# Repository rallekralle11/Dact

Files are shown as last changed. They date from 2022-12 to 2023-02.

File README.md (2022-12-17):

# Dact

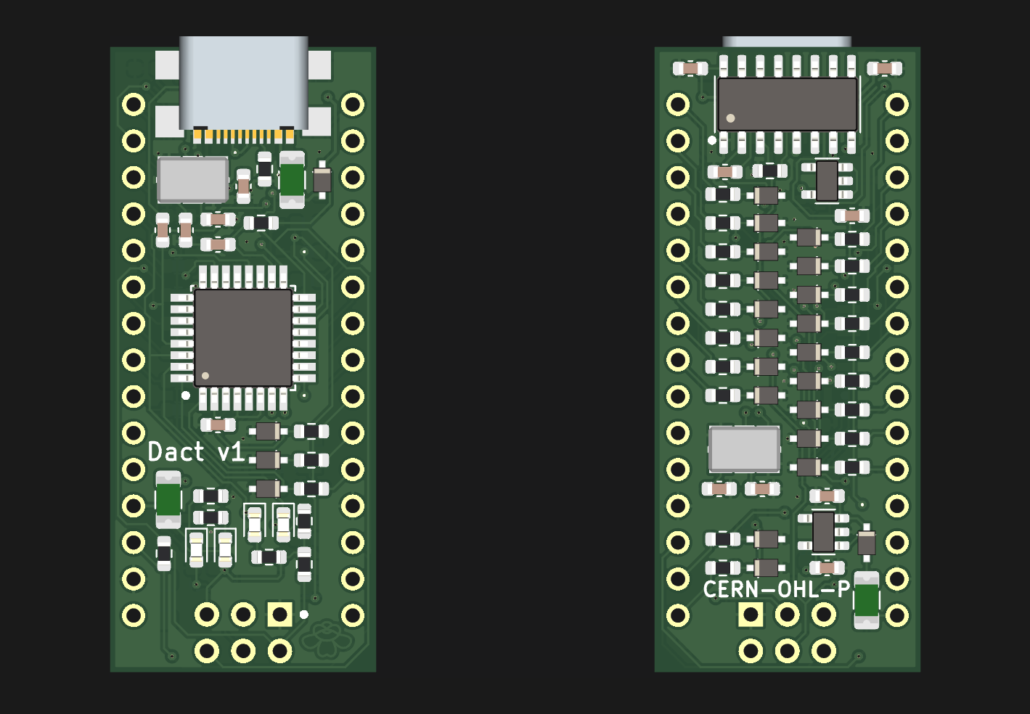
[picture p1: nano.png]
board


With overcurrent(short) and overvoltage protection on all IO pins, VIN reverse polarity and short protection, USB and MCU overcurrent protection as well as reset pin overvoltage protection. And USB-C.

Lacks 5 and 3V pin overvoltage protection, i tried but it wouldn't fit. Amazed i managed to fit this many features on it in general, and with 1608 components as well.

Of course there are tradeoffs, the onboard 5V regulator can only supply 150mA, there's no reset button and there's no way i could fit all pin identifiers, so i didn't add any.

Licensed under CERN-OHL-P

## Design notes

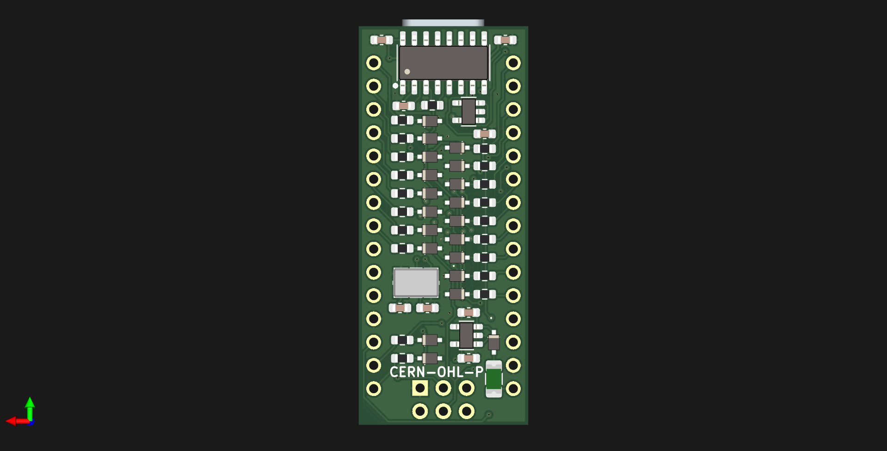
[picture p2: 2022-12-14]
DactB.png

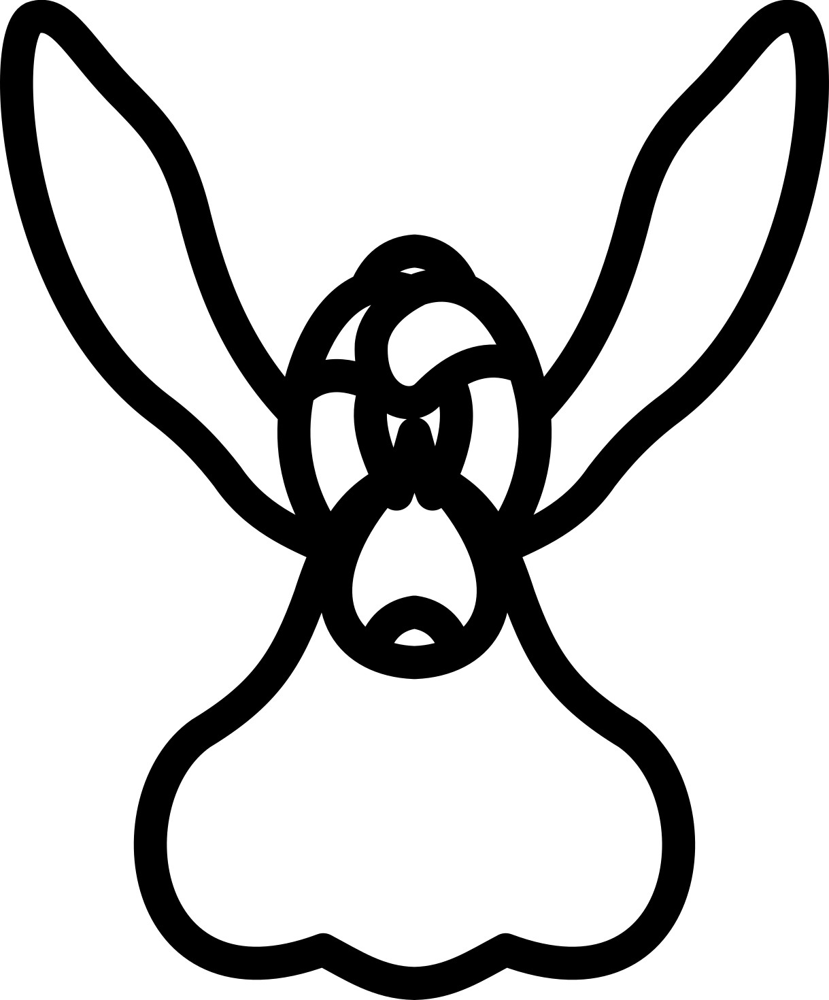
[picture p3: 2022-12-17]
maculata.png

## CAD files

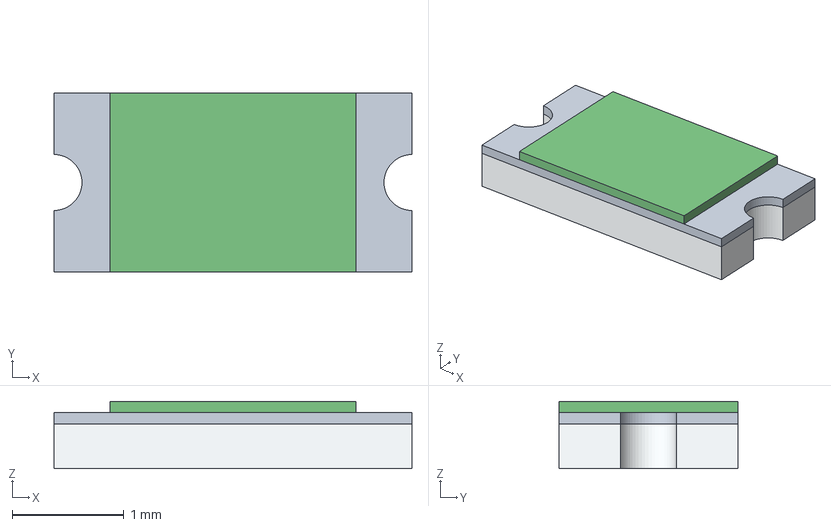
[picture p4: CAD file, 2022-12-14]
fuse.stp
3.20 x 1.60 x 0.6 mm

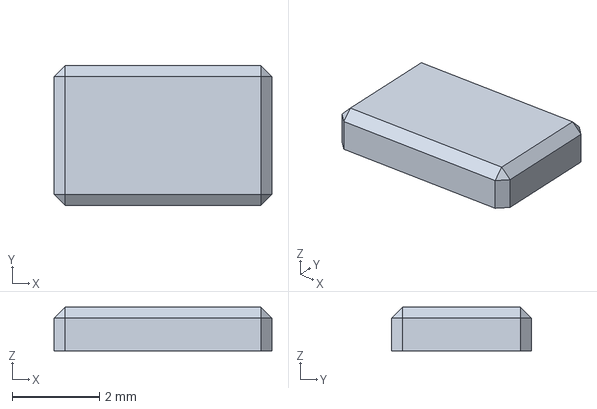
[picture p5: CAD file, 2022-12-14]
crystal.stp
5.00 x 3.20 x 1.00 mm

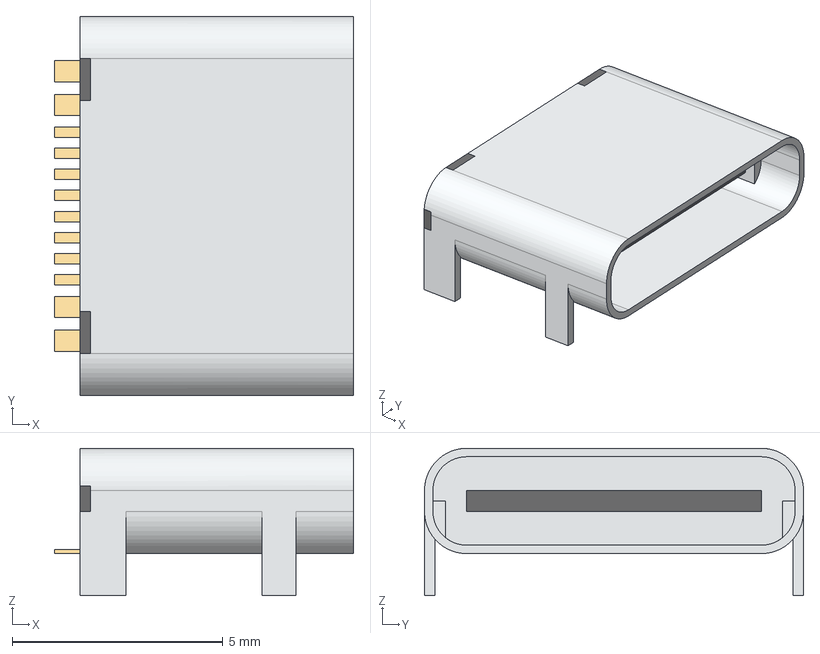
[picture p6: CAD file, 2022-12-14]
USBC.stp
7.10 x 9.00 x 3.50 mm

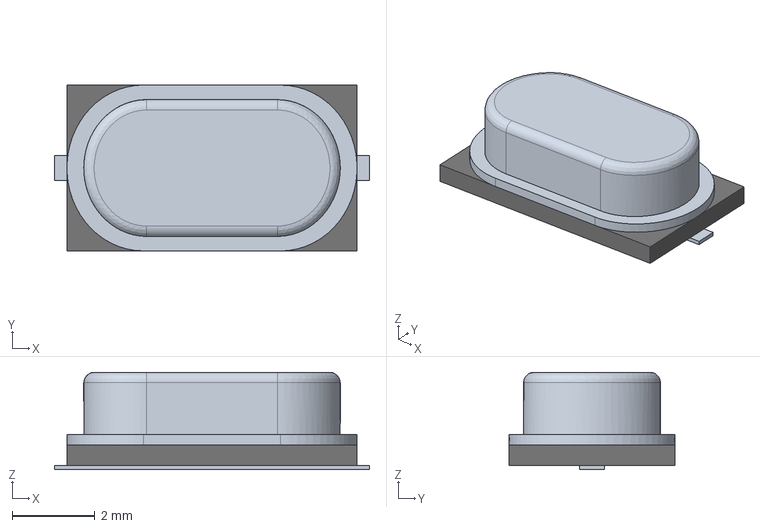
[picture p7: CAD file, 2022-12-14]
crystal2.stp
7.60 x 4.00 x 2.35 mm

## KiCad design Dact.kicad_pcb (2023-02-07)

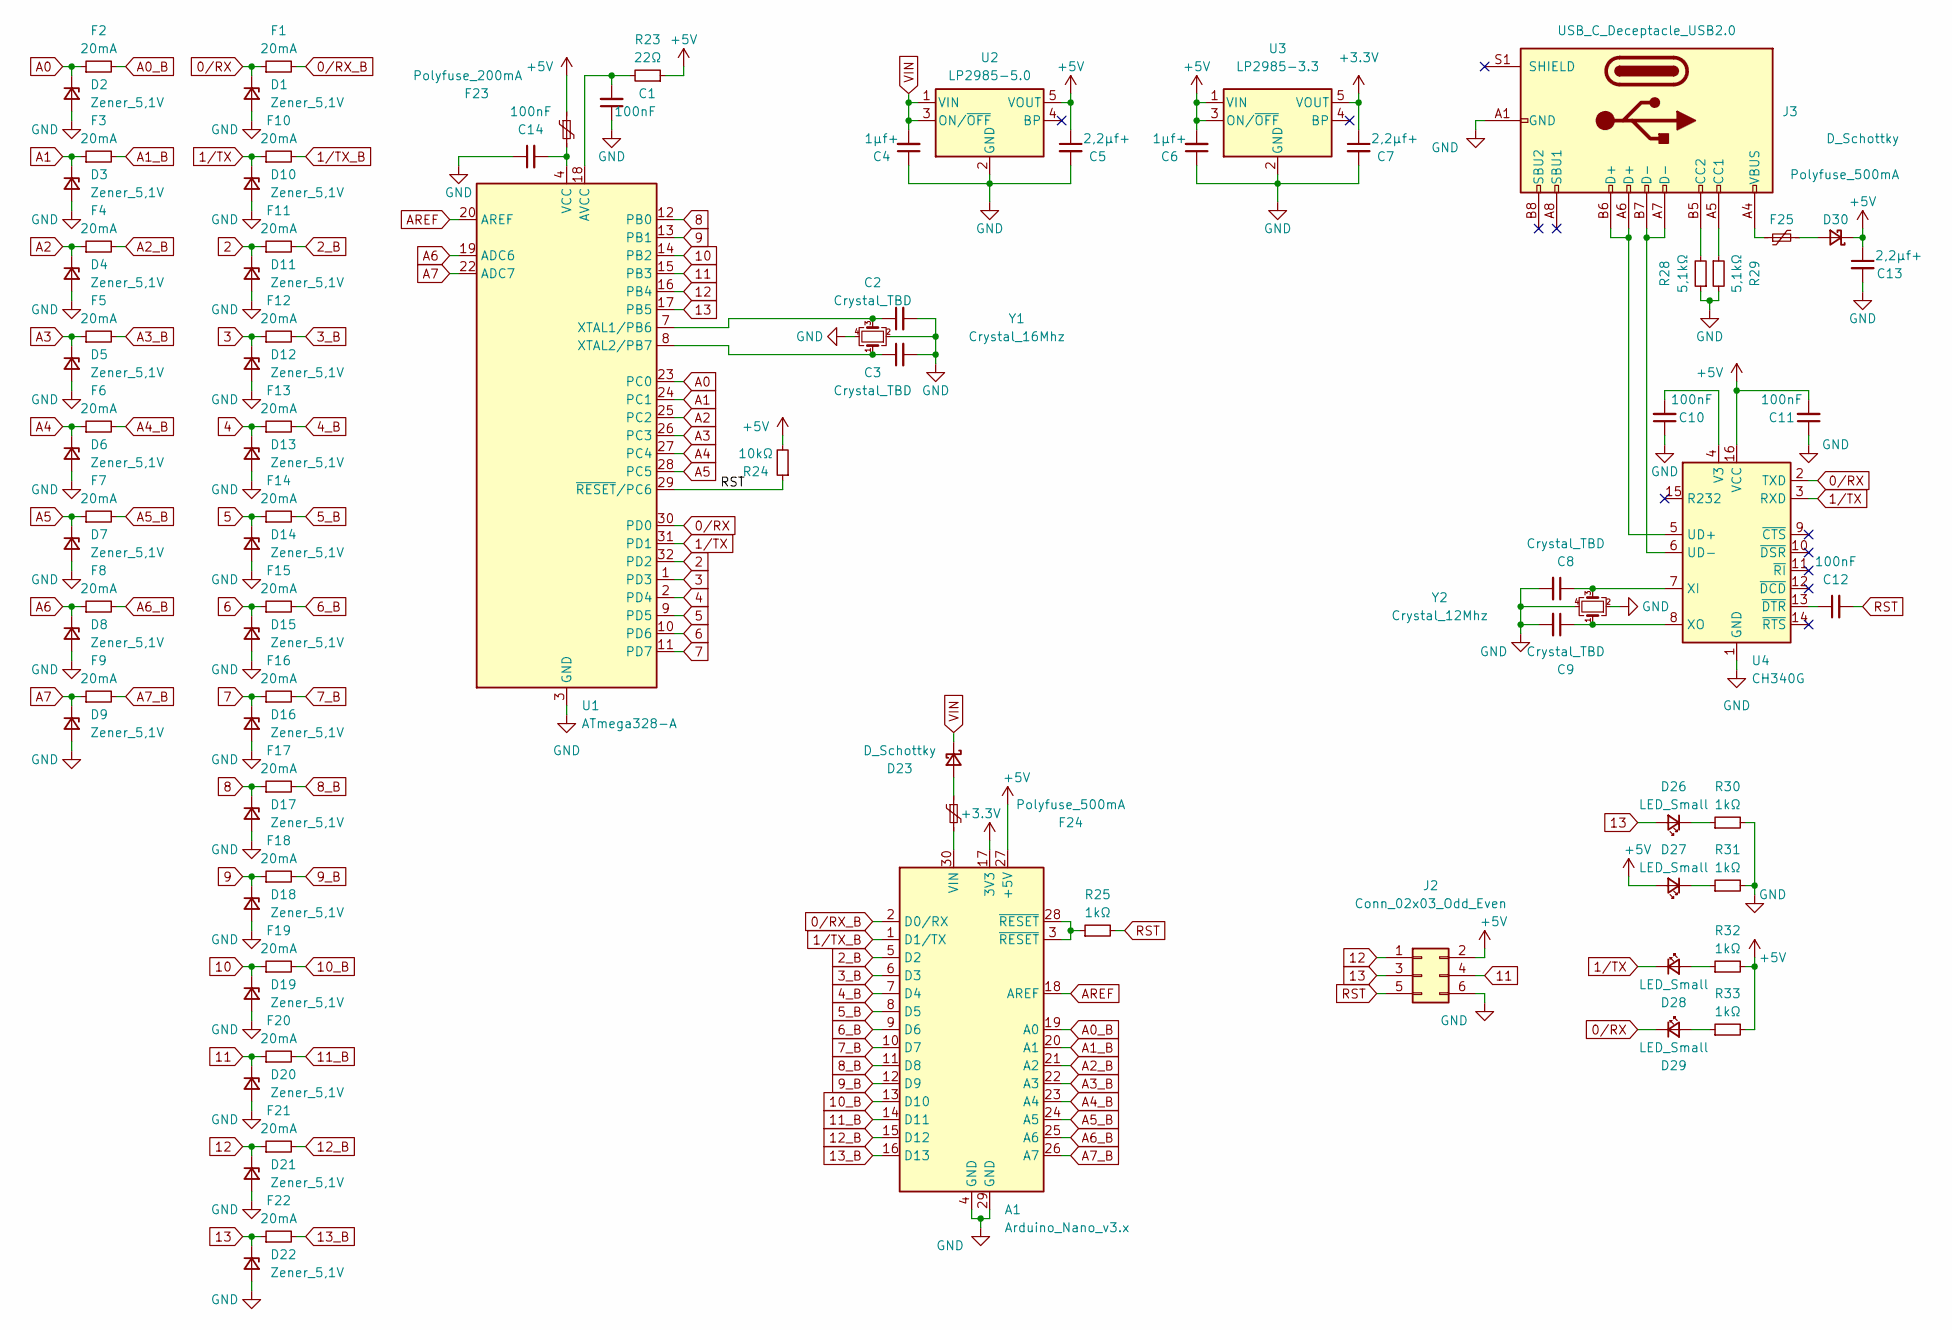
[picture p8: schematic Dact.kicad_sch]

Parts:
A1: Arduino_Nano_v3.x; Arduino_Nano
C1, C10, C11, C12, C14: 100nF; C_0603_1608Metric
C2, C3, C8, C9: Crystal_TBD; C_0603_1608Metric
C4, C6: 1µf+; C_0603_1608Metric
C5, C7, C13: 2,2µf+; C_0603_1608Metric
D1, D2, D3, D4, D5, D6, D7, D8, D9, D10, D11, D12, D13, D14, D15, D16, D17, D18, D19, D20, D21, D22: Zener_5,1V; SOD323_bättre
D23, D30: D_Schottky; SOD323_bättre
D26, D27, D28, D29: LED_Small; LED_0603_1608Metric
F1, F2, F3, F4, F5, F6, F7, F8, F9, F10, F11, F12, F13, F14, F15, F16, F17, F18, F19, F20, F21, F22: 20mA; R_0603_1608Metric
F23: Polyfuse_200mA; Fuse_1206_3216Metric
F24, F25: Polyfuse_500mA; Fuse_1206_3216Metric
J2: Conn_02x03_Odd_Even; PinHeader_2x03_P2.54mm_Vertical
J3: USB_C_Deceptacle_USB2.0; TYPE-C-SMD
R23: 22Ω; R_0603_1608Metric
R24: 10kΩ; R_0603_1608Metric
R25, R30, R31, R32, R33: 1kΩ; R_0603_1608Metric
R28, R29: 5,1kΩ; R_0603_1608Metric
U1: ATmega328-A; TQFP-32_7x7mm_P0.8mm
U2: LP2985-5.0; SOT-23-5
U3: LP2985-3.3; SOT-23-5
U4: CH340G; SOIC-16_3.9x9.9mm_P1.27mm
Y1: Crystal_16Mhz; Crystal_SMD_5032-4Pin_5.0x3.2mm
Y2: Crystal_12Mhz; Crystal_SMD_5032-4Pin_5.0x3.2mm

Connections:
0/RX: D1.1 (K), D29.1 (K), F1.1, U1.30 (PD0), U4.2 (TXD)
0/RX_B: A1.2 (D0/RX), F1.2
1/TX: D10.1 (K), D28.1 (K), F10.1, U1.31 (PD1), U4.3 (RXD)
1/TX_B: A1.1 (D1/TX), F10.2
2: D11.1 (K), F11.1, U1.32 (PD2)
2_B: A1.5 (D2), F11.2
3: D12.1 (K), F12.1, U1.1 (PD3)
3_B: A1.6 (D3), F12.2
4: D13.1 (K), F13.1, U1.2 (PD4)
4_B: A1.7 (D4), F13.2
5: D14.1 (K), F14.1, U1.9 (PD5)
5_B: A1.8 (D5), F14.2
6: D15.1 (K), F15.1, U1.10 (PD6)
6_B: A1.9 (D6), F15.2
7: D16.1 (K), F16.1, U1.11 (PD7)
7_B: A1.10 (D7), F16.2
8: D17.1 (K), F17.1, U1.12 (PB0)
8_B: A1.11 (D8), F17.2
9: D18.1 (K), F18.1, U1.13 (PB1)
9_B: A1.12 (D9), F18.2
10: D19.1 (K), F19.1, U1.14 (PB2)
10_B: A1.13 (D10), F19.2
11: D20.1 (K), F20.1, J2.4, U1.15 (PB3)
11_B: A1.14 (D11), F20.2
12: D21.1 (K), F21.1, J2.1, U1.16 (PB4)
12_B: A1.15 (D12), F21.2
13: D22.1 (K), D26.2 (A), F22.1, J2.3, U1.17 (PB5)
13_B: A1.16 (D13), F22.2
+3.3V: A1.17 (3V3), C7.1, U3.5 (VOUT)
+5V: A1.27 (+5V), C5.1, C6.2, C11.2, C13.1, D27.2 (A), D30.1 (K), F23.1, J2.2, R23.1, R24.2, R32.2, R33.2, U2.5 (VOUT), U3.1 (VIN), U3.3 (ON/~OFF), U4.16 (VCC)
A0: D2.1 (K), F2.1, U1.23 (PC0)
A0_B: A1.19 (A0), F2.2
A1: D3.1 (K), F3.1, U1.24 (PC1)
A1_B: A1.20 (A1), F3.2
A2: D4.1 (K), F4.1, U1.25 (PC2)
A2_B: A1.21 (A2), F4.2
A3: D5.1 (K), F5.1, U1.26 (PC3)
A3_B: A1.22 (A3), F5.2
A4: D6.1 (K), F6.1, U1.27 (PC4)
A4_B: A1.23 (A4), F6.2
A5: D7.1 (K), F7.1, U1.28 (PC5)
A5_B: A1.24 (A5), F7.2
A6: D8.1 (K), F8.1, U1.19 (ADC6)
A6_B: A1.25 (A6), F8.2
A7: D9.1 (K), F9.1, U1.22 (ADC7)
A7_B: A1.26 (A7), F9.2
AREF: A1.18 (AREF), U1.20 (AREF)
GND: A1.4 (GND), A1.29 (GND), C1.1, C2.2, C3.2, C4.1, C5.2, C6.1, C7.2, C8.2, C9.2, C10.1, C11.1, C13.2, C14.1, D1.2 (A), D2.2 (A), D3.2 (A), D4.2 (A), D5.2 (A), D6.2 (A), D7.2 (A), D8.2 (A), D9.2 (A), D10.2 (A), D11.2 (A), D12.2 (A), D13.2 (A), D14.2 (A), D15.2 (A), D16.2 (A), D17.2 (A), D18.2 (A), D19.2 (A), D20.2 (A), D21.2 (A), D22.2 (A), J2.6, J3.A1 (GND), J3.A12 (GND), J3.B1 (GND), J3.B12 (GND), R28.1, R29.2, R30.2, R31.2, U1.3 (GND), U1.5 (GND), U1.21 (GND), U2.2 (GND), U3.2 (GND), U4.1 (GND), Y1.2, Y1.4, Y2.2, Y2.4
unnamed: A1.3 (~RESET), A1.28 (~RESET), R25.1
unnamed: A1.30 (VIN), F24.2
unnamed: C1.2, R23.2, U1.18 (AVCC)
unnamed: C2.1, U1.7 (XTAL1/PB6), Y1.3
unnamed: C3.1, U1.8 (XTAL2/PB7), Y1.1
unnamed: C8.1, U4.7 (XI), Y2.3
unnamed: C9.1, U4.8 (XO), Y2.1
unnamed: C10.2, U4.4 (V3)
unnamed: C12.1, U4.13 (~DTR)
unnamed: C14.2, F23.2, U1.4 (VCC), U1.6 (VCC)
unnamed: D23.2 (A), F24.1
unnamed: D26.1 (K), R30.1
unnamed: D27.1 (K), R31.1
unnamed: D28.2 (A), R32.1
unnamed: D29.2 (A), R33.1
unnamed: D30.2 (A), F25.2
unnamed: F25.1, J3.A4 (VBUS), J3.A9 (VBUS), J3.B4 (VBUS), J3.B9 (VBUS)
unnamed: J3.A5 (CC1), R29.1
unnamed: J3.A6 (D+), J3.B6 (D+), U4.5 (UD+)
unnamed: J3.A7 (D-), J3.B7 (D-), U4.6 (UD-)
unnamed: J3.B5 (CC2), R28.2
RST: C12.2, J2.5, R24.1, R25.2, U1.29 (~RESET/PC6)
VIN: C4.2, D23.1 (K), U2.1 (VIN), U2.3 (ON/~OFF)

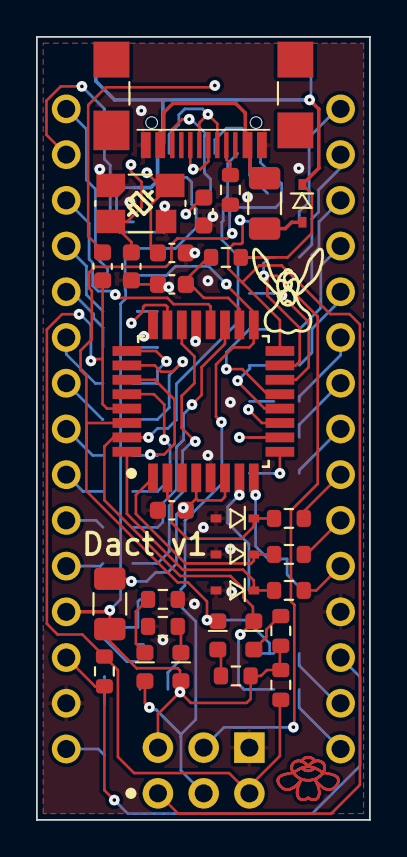
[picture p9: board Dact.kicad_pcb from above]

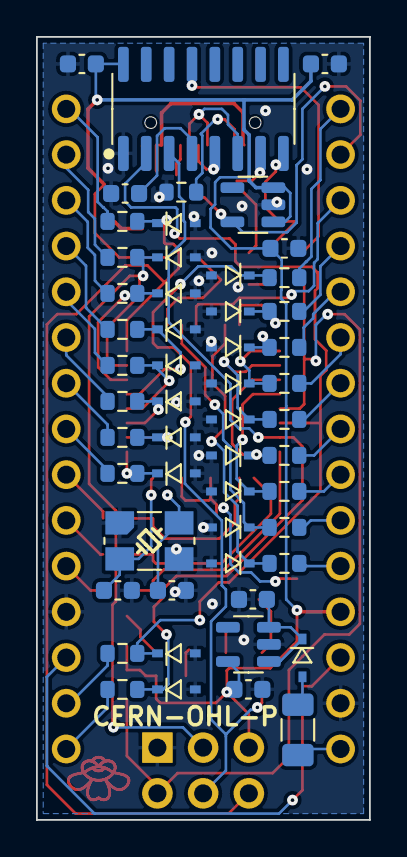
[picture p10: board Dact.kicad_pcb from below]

Board: 2 copper layers, 18.5 x 43.5 mm, 85 parts (53 on the bottom side), 71 nets.

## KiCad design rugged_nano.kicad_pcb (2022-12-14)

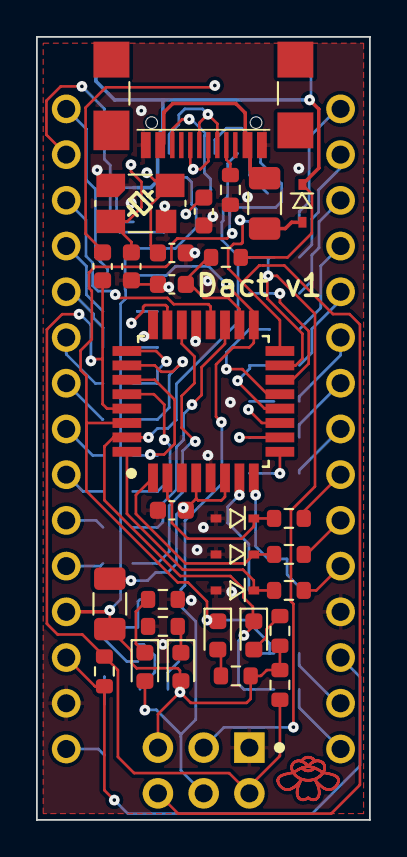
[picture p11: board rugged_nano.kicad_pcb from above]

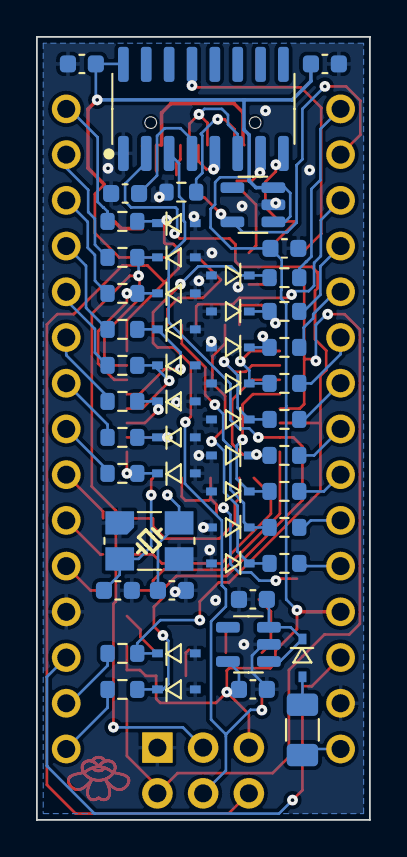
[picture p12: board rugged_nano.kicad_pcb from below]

Board: 2 copper layers, 18.5 x 43.5 mm, 85 parts (53 on the bottom side), 71 nets.

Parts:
A1: Arduino_Nano_v3.x; Arduino_Nano
C1: 1µF; C_0603_1608Metric
C2, C3, C8, C9: Crystal_TBD; C_0603_1608Metric
C4, C6: 1µf+; C_0603_1608Metric
C5, C7, C13: 2,2µf+; C_0603_1608Metric
C10, C11, C12, C14: 100nF; C_0603_1608Metric
D1, D2, D3, D4, D5, D6, D7, D8, D9, D10, D11, D12, D13, D14, D15, D16, D17, D18, D19, D20, D21, D22: Zener_5,1V; SOD323_bättre
D23, D30: D_Schottky; SOD323_bättre
D26, D27, D28, D29: LED_Small; LED_0603_1608Metric
F1: Polyfuse_200mA; Fuse_1206_3216Metric
F2: Polyfuse_1A; Fuse_1206_3216Metric
F3: Polyfuse_500mA; Fuse_1206_3216Metric
J2: Conn_02x03_Odd_Even; PinHeader_2x03_P2.54mm_Vertical
J3: USB_C_Receptacle_USB2.0; TYPE-C-SMD
R1, R2, R3, R4, R5, R6, R7, R8, R9, R10, R11, R12, R13, R14, R15, R16, R17, R18, R19, R20, R21, R22: 220Ω; R_0603_1608Metric
R23, R24: 10kΩ; R_0603_1608Metric
R25, R30, R31, R32, R33: 1kΩ; R_0603_1608Metric
R28, R29: 5,1kΩ; R_0603_1608Metric
U1: ATmega328-A; TQFP-32_7x7mm_P0.8mm
U2: LP2985-5.0; SOT-23-5
U3: LP2985-3.3; SOT-23-5
U4: CH340G; SOIC-16_3.9x9.9mm_P1.27mm
Y1, Y2: Crystal_GND24_Small; Crystal_SMD_5032-4Pin_5.0x3.2mm

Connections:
0/RX: D1.1 (K), D29.1 (K), R1.1, U1.30 (PD0), U4.2 (TXD)
0/RX_B: A1.2 (D0/RX), R1.2
1/TX: D10.1 (K), D28.1 (K), R10.1, U1.31 (PD1), U4.3 (RXD)
1/TX_B: A1.1 (D1/TX), R10.2
2: D11.1 (K), R11.1, U1.32 (PD2)
2_B: A1.5 (D2), R11.2
3: D12.1 (K), R12.1, U1.1 (PD3)
3_B: A1.6 (D3), R12.2
4: D13.1 (K), R13.1, U1.2 (PD4)
4_B: A1.7 (D4), R13.2
5: D14.1 (K), R14.1, U1.9 (PD5)
5_B: A1.8 (D5), R14.2
6: D15.1 (K), R15.1, U1.10 (PD6)
6_B: A1.9 (D6), R15.2
7: D16.1 (K), R16.1, U1.11 (PD7)
7_B: A1.10 (D7), R16.2
8: D17.1 (K), R17.1, U1.12 (PB0)
8_B: A1.11 (D8), R17.2
9: D18.1 (K), R18.1, U1.13 (PB1)
9_B: A1.12 (D9), R18.2
10: D19.1 (K), R19.1, U1.14 (PB2)
10_B: A1.13 (D10), R19.2
11: D20.1 (K), J2.4, R20.1, U1.15 (PB3)
11_B: A1.14 (D11), R20.2
12: D21.1 (K), J2.1, R21.1, U1.16 (PB4)
12_B: A1.15 (D12), R21.2
13: D22.1 (K), D26.2 (A), J2.3, R22.1, U1.17 (PB5)
13_B: A1.16 (D13), R22.2
+3.3V: A1.17 (3V3), C7.1, U3.5 (VOUT)
+5V: A1.27 (+5V), C5.1, C6.2, C11.2, C13.1, D27.2 (A), D30.1 (K), F1.1, J2.2, R23.1, R24.2, R32.2, R33.2, U2.5 (VOUT), U3.1 (VIN), U3.3 (ON/~OFF), U4.16 (VCC)
A0: D2.1 (K), R2.1, U1.23 (PC0)
A0_B: A1.19 (A0), R2.2
A1: D3.1 (K), R3.1, U1.24 (PC1)
A1_B: A1.20 (A1), R3.2
A2: D4.1 (K), R4.1, U1.25 (PC2)
A2_B: A1.21 (A2), R4.2
A3: D5.1 (K), R5.1, U1.26 (PC3)
A3_B: A1.22 (A3), R5.2
A4: D6.1 (K), R6.1, U1.27 (PC4)
A4_B: A1.23 (A4), R6.2
A5: D7.1 (K), R7.1, U1.28 (PC5)
A5_B: A1.24 (A5), R7.2
A6: D8.1 (K), R8.1, U1.19 (ADC6)
A6_B: A1.25 (A6), R8.2
A7: D9.1 (K), R9.1, U1.22 (ADC7)
A7_B: A1.26 (A7), R9.2
AREF: A1.18 (AREF), U1.20 (AREF)
GND: A1.4 (GND), A1.29 (GND), C1.1, C2.2, C3.2, C4.1, C5.2, C6.1, C7.2, C8.2, C9.2, C10.1, C11.1, C13.2, C14.1, D1.2 (A), D2.2 (A), D3.2 (A), D4.2 (A), D5.2 (A), D6.2 (A), D7.2 (A), D8.2 (A), D9.2 (A), D10.2 (A), D11.2 (A), D12.2 (A), D13.2 (A), D14.2 (A), D15.2 (A), D16.2 (A), D17.2 (A), D18.2 (A), D19.2 (A), D20.2 (A), D21.2 (A), D22.2 (A), J2.6, J3.A1 (GND), J3.A12 (GND), J3.B1 (GND), J3.B12 (GND), R28.1, R29.2, R30.2, R31.2, U1.3 (GND), U1.5 (GND), U1.21 (GND), U2.2 (GND), U3.2 (GND), U4.1 (GND), Y1.2, Y1.4, Y2.2, Y2.4
unnamed: A1.3 (~RESET), A1.28 (~RESET), R25.1
unnamed: A1.30 (VIN), F2.2
unnamed: C1.2, R23.2, U1.18 (AVCC)
unnamed: C2.1, U1.7 (XTAL1/PB6), Y1.3
unnamed: C3.1, U1.8 (XTAL2/PB7), Y1.1
unnamed: C8.1, U4.7 (XI), Y2.3
unnamed: C9.1, U4.8 (XO), Y2.1
unnamed: C10.2, U4.4 (V3)
unnamed: C12.1, U4.13 (~DTR)
unnamed: C14.2, F1.2, U1.4 (VCC), U1.6 (VCC)
unnamed: D23.2 (A), F2.1
unnamed: D26.1 (K), R30.1
unnamed: D27.1 (K), R31.1
unnamed: D28.2 (A), R32.1
unnamed: D29.2 (A), R33.1
unnamed: D30.2 (A), F3.2
unnamed: F3.1, J3.A4 (VBUS), J3.A9 (VBUS), J3.B4 (VBUS), J3.B9 (VBUS)
unnamed: J3.A5 (CC1), R29.1
unnamed: J3.A6 (D+), J3.B6 (D+), U4.5 (UD+)
unnamed: J3.A7 (D-), J3.B7 (D-), U4.6 (UD-)
unnamed: J3.B5 (CC2), R28.2
RST: C12.2, J2.5, R24.1, R25.2, U1.29 (~RESET/PC6)
VIN: C4.2, D23.1 (K), U2.1 (VIN), U2.3 (ON/~OFF)

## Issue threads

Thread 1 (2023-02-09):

Compiler support

Anobium, 2023-02-09:
I am the key developer for Great Cow BASIC.  A very easy to compiler and tool chain.

This project makes a lot sense.  Well done.

I am willing to add this chip / solution to our compiler.

When and how can I get a 2nd revision ( I think the 1st released has issues ) board ?

Evan

rallekralle11, 2023-02-10:
no.

Anobium, 2023-02-10:
No?

What is the plan? Another revision ? No boards? Not interested in a wider development into other languages?

Help me understand. Thanks.

rallekralle11, 2023-02-10:
i will make other revisions, but i don't really know what you want with it.
it's an arduino nano, you can develop for that and it'll work on this

Anobium, 2023-02-10:
Ok. The chip is a mega328a.  When you get another revision of the board then we could publish a set of demos for the board.

Closed 2023-02-10.

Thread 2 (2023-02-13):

Suggestion: Use Resistor Arrays

nkappler, 2023-02-13:
In the readme you mentioned that you tried adding overvoltage protection for the 3V and 5V pins but it didn't fit.
You could try to use resistor arrays to reduce part count and make more space available...
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

rallekralle11, 2023-02-13:
thanks for the suggestion! it doesn't have too many resistors, but for the next version it might be a good idea

nkappler, 2023-02-16:
I think there are array version of all sorts of components: capacitors, LEDs, diodes, etc...
Especially on the backside there seems to be a lot of repetition, so it might boil down the space requirements quite a bit :)

rallekralle11, 2023-02-16:
if there are zener diode arrays that would help a lot. i'll look into it

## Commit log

2022-12-14 bit of everything
    [Dact.kicad_pcb, Dact.kicad_sch]
2022-12-14 small changes
    [Dact.kicad_pcb]
2022-12-14 tiny change
    [Dact-B_Cu.gbr, Dact-B_Mask.gbr, Dact-B_Paste.gbr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]
2022-12-15 updated gerbers
    [Dact-B_Cu.gbr, Dact-B_Mask.gbr, Dact-B_Paste.gbr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]
2022-12-17 redid some designators and things
    [Dact-B_Cu.gbr, Dact-B_Mask.gbr, Dact-B_Paste.gbr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]
2023-01-06 BOM update
    [Dact.kicad_sch]
2023-02-07 slight update
    [Dact-B_Cu.gbr, Dact-B_Mask.gbr, Dact-B_Paste.gbr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]
